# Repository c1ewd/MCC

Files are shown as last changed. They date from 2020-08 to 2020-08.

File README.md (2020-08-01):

# Microclimate controller (MCC)







> Project based STM32F030K6T6

## Dependensies

- CMSIS

## Clone

> Clone this repo to your local machine using `git clone https://github.com/c1ewd/MCC`

## Features

> Device intended for measuring humidity and temperature. By deviation from specified range of temperature or humidity it send sound signal.
> Hardware design was making in Eagle CAD. Software was coding in IAR.
> Device is using digital humidity and temperature sensor AM2302. For sound signal using EFM-475. For graphical interface using Nokia 5110 display.

## Donations (Optional)

Liberapay (https://liberapay.com/c1ewd/donate)

## License

- **[MIT license](http://opensource.org/licenses/mit-license.php)**
- Copyright © 2020 <a href="https://teleg.run/c1ewd" target="_blank">c1ewd</a>.

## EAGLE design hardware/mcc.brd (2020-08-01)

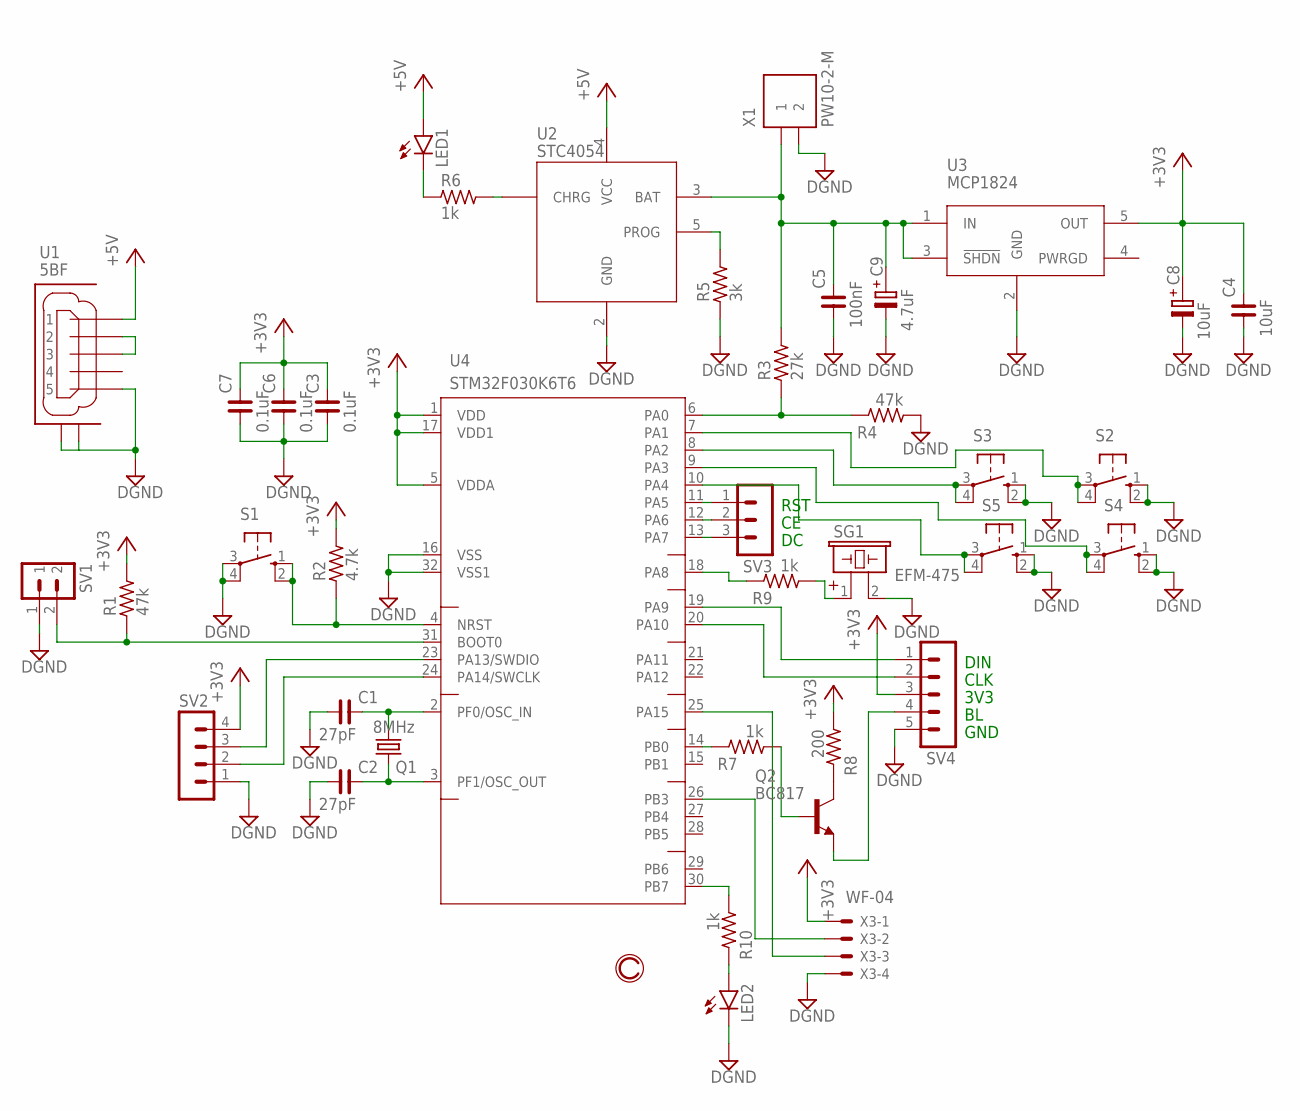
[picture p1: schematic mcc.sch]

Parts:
C1, C2: 27pF; C0805
C3, C6, C7: 0.1uF; C0805
C4: 10uF; C1206
C5: 100nF; C0805
C8: 10uF; SV-C
C9: 4.7uF; SV-C
LED1, LED2: LEDSML0805; SML0805
Q1: 8MHz; HC49UP
Q2: BC817; SOT23-BEC
R1, R4: 47k; R0805
R2: 4.7k; R0805
R3: 27k; R0805
R5: 3k; R0805
R6, R7, R9, R10: 1k; R0805
R8: 200; R0805
S1, S2, S3, S4, S5: 10-XX; B3F-10XX
SG1: EFM-475; EFM-472
SV1: MA02-1
SV2: MA04-1
SV3: MA03-1
SV4: MA05-1
U1: 5BF; MICRO-USB-5BF
U2: STC4054; SOT23-5L
U3: MCP1824; SOT23-5L
U4: STM32F030K6T6; LQFP-32
X1: PW10-2-M; MKS1852-6-0-202
X3: WF-04; 22-23-2041

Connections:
+3V3: C3.2, C4.2, C6.2, C7.2, C8.+, R1.2, R2.2, R8.1, SV2.4, SV4.3, U3.5 (OUT), U4.1 (VDD), U4.5 (VDDA), U4.17 (VDD1), X3.1
BAT: C5.2, C9.+, R3.2, U2.3 (BAT), U3.1 (IN), U3.3 (!SHDN), X1.1
BL: R7.2, U4.14 (PB0)
BOOT0: R1.1, SV1.2, U4.31 (BOOT0)
BUZZER: R9.2, U4.18 (PA8)
CE: SV3.2, U4.12 (PA6)
CHRG: R6.2, U2.1 (CHRG)
CLK: SV4.2, U4.20 (PA10)
DATA: U4.26 (PB3), X3.2
DC: SV3.3, U4.13 (PA7)
DGND: C1.1, C2.1, C3.1, C4.1, C5.1, C6.1, C7.1, C8.-, C9.-, LED2.C, R4.1, R5.1, S1.3, S1.4 (P1), S2.1 (S), S2.2 (S1), S3.1 (S), S3.2 (S1), S4.1 (S), S4.2 (S1), S5.1 (S), S5.2 (S1), SG1.2, SV1.1, SV2.1, SV4.5, U1.5, U1.GND1, U1.GND2, U2.2 (GND), U3.2 (GND), U4.16 (VSS), U4.32 (VSS1), X1.2, X3.4
DIN: SV4.1, U4.19 (PA9)
DIV_BAT: R3.1, R4.2, U4.6 (PA0)
LED2: R10.1, U4.30 (PB7)
unnamed: U4.25 (PA15), X3.3
unnamed: U1.2, U1.3
NRST: R2.1, S1.1 (S), S1.2 (S1), U4.4 (NRST)
PF0-OSC_IN: C1.2, Q1.1, U4.2 (PF0/OSC_IN)
PF1-OSC_OUT: C2.2, Q1.2, U4.3 (PF1/OSC_OUT)
PROG: R5.2, U2.5 (PROG)
RST: SV3.1, U4.11 (PA5)
R_+3V3: Q2.C, R8.2
R_BL: Q2.B, R7.1
R_BUZZER: R9.1, SG1.1
R_CHRG: LED1.C, R6.1
R_LED2: LED2.A, R10.2
S2: S2.3, S2.4 (P1), U4.7 (PA1)
S3: S3.3, S3.4 (P1), U4.8 (PA2)
S4: S4.3, S4.4 (P1), U4.9 (PA3)
S5: S5.3, S5.4 (P1), U4.10 (PA4)
SWCLK: SV2.2, U4.24 (PA14/SWCLK)
SWDIO: SV2.3, U4.23 (PA13/SWDIO)
VCC: LED1.A, U1.1, U2.4 (VCC)
Е_BL: Q2.E, SV4.4

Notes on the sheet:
RST
DIN
CLK
3V3
GND

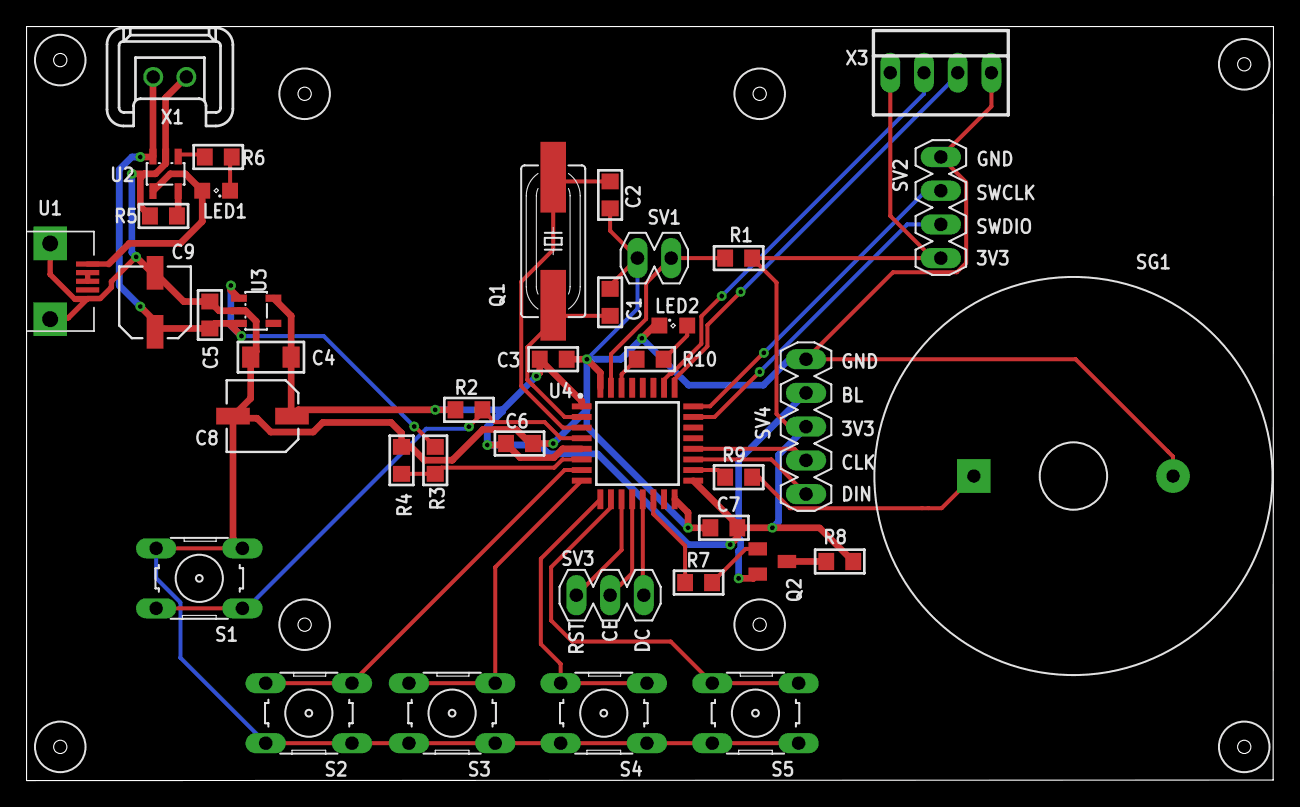
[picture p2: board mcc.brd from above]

Board: 2 copper layers, 94.0 x 56.8 mm, 39 parts (0 on the bottom side), 34 nets.

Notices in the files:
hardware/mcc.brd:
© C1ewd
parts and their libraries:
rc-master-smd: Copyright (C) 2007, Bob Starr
